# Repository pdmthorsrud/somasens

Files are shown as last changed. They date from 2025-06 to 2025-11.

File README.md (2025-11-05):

# SomaSens

A haptic feedback system that translates Pushbullet notifications into physical vibration patterns using Arduino-controlled motors.

## Hardware Photos

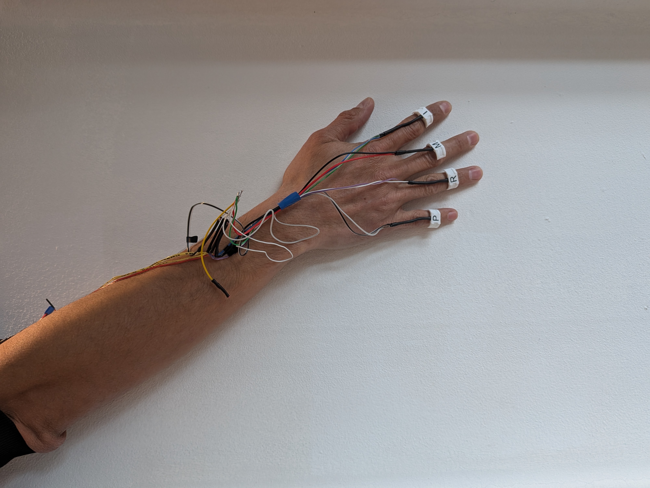
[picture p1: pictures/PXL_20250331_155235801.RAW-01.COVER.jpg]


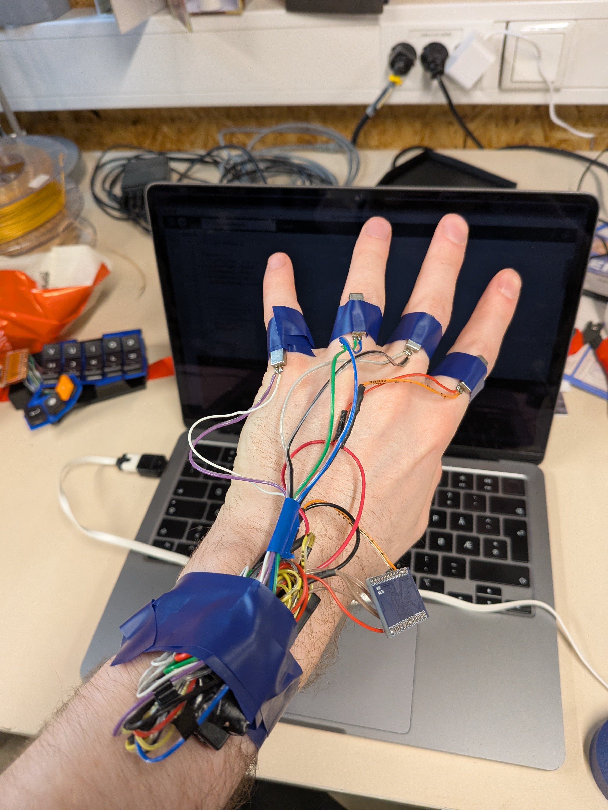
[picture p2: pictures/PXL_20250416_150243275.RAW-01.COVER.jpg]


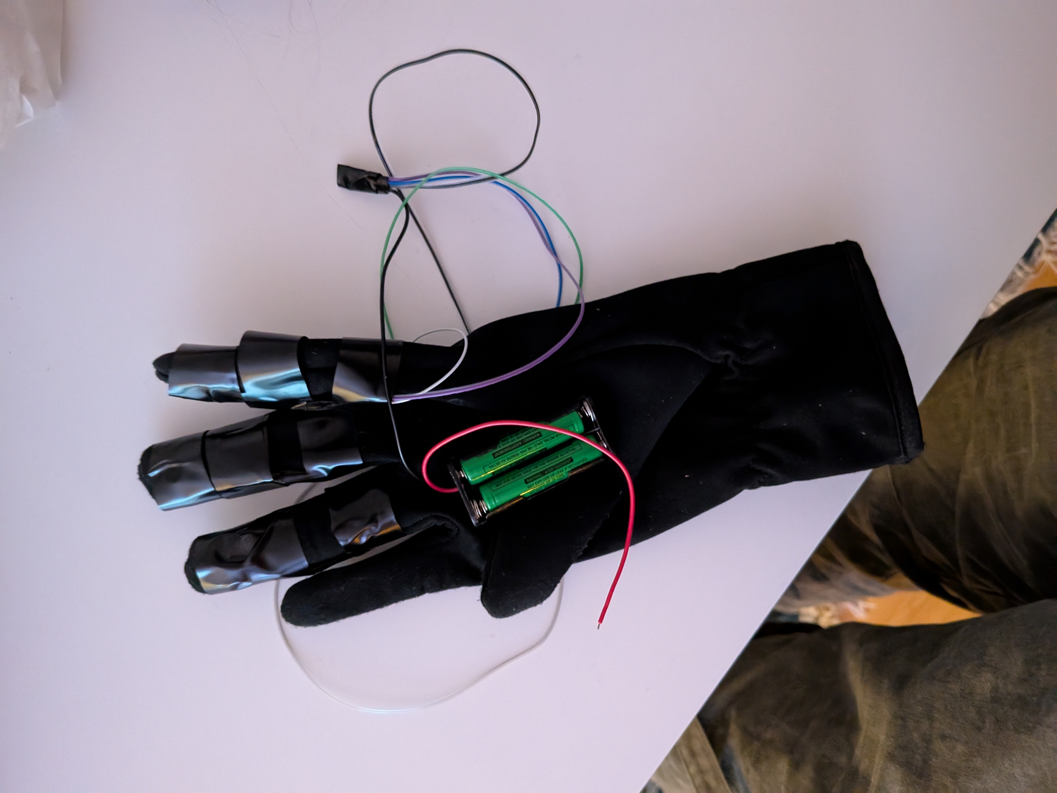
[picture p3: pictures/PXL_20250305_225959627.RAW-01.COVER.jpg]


## System Architecture

```mermaid
graph TB
    subgraph "Mobile Device"
        A[Notification Event]
    end

    subgraph "Pushbullet Cloud"
        B[Pushbullet API]
        C[WebSocket Stream]
    end

    subgraph "Python Host main.py"
        D[WebSocket Listener]
        E[Pushbullet Listener<br/>pushbullet_listener.py]
        F[Notification Interpreter]
        G[Haptic Controller<br/>haptic_controller.py]
    end

    subgraph "Arduino Hardware"
        H[Serial Interface<br/>115200 baud]
        I[Haptic HAL<br/>haptic_hal.ino]
        J1[Motor 1<br/>Pin 3]
        J2[Motor 2<br/>Pin 5]
        J3[Motor 3<br/>Pin 6]
        J4[Motor 4<br/>Pin 9]
    end

    A -->|Push Event| B
    B -->|WebSocket| C
    C -->|JSON Message| D
    D --> E
    E -->|Notification Data| F
    F -->|Haptic Pattern| G
    G -->|Serial Command<br/>v:motor:intensity:duration| H
    H --> I
    I -->|PWM Signal| J1
    I -->|PWM Signal| J2
    I -->|PWM Signal| J3
    I -->|PWM Signal| J4

    style A fill:#e1f5ff
    style B fill:#ffe1e1
    style C fill:#ffe1e1
    style D fill:#fff4e1
    style E fill:#fff4e1
    style F fill:#fff4e1
    style G fill:#fff4e1
    style H fill:#e1ffe1
    style I fill:#e1ffe1
    style J1 fill:#f0e1ff
    style J2 fill:#f0e1ff
    style J3 fill:#f0e1ff
    style J4 fill:#f0e1ff
```

## How It Works

### 1. Notification Flow

When a notification arrives on your mobile device, it flows through the system as follows:

1. **Mobile Device** generates a notification event
2. **Pushbullet** captures the notification and sends it to the cloud
3. **WebSocket Stream** broadcasts the notification in real-time
4. **Python Host** receives and processes the notification

### 2. Python Processing Layer

The Python application consists of three main components:

#### main.py
- Entry point of the application
- Manages WebSocket connection lifecycle
- Coordinates between listener and controller
- Handles graceful shutdown

#### pushbullet_listener.py
- Connects to Pushbullet WebSocket stream
- Parses incoming JSON messages
- Interprets notifications and maps them to haptic patterns
- Currently defaults to `all_vibrate` pattern for all notifications

#### haptic_controller.py
- Manages serial communication with Arduino
- Provides haptic pattern primitives:
  - `left_to_right()` - Sequential vibration from left to right
  - `right_to_left()` - Sequential vibration from right to left
  - `all_vibrate()` - Simultaneous vibration of all motors
  - `confirm()` - Double-tap pattern
  - `cancel()` - Fading pulse pattern
- Sends formatted commands over serial to Arduino

### 3. Serial Protocol

Commands are sent from Python to Arduino over serial at 115200 baud:

```
v:motor_id:intensity:duration_ms
```

Example:
```
v:1:1.0:500  # Vibrate motor 1 at 100% intensity for 500ms
```

### 4. Arduino Hardware Layer

#### haptic_hal.ino
- Receives serial commands
- Parses vibration instructions
- Controls 4 motors via PWM pins (3, 5, 6, 9)
- Manages concurrent vibration events
- Automatically stops vibrations after specified duration

The Arduino tracks active vibration events for each motor and updates them in the main loop, allowing multiple motors to vibrate simultaneously with different durations.

## Hardware Setup

### Bill of Materials

For a complete list of components and purchase links, see [BOM.md](BOM.md).

Key components:
- Pro Micro ATmega32U4 (USB Type-C)
- 4x Linear vibration motors (0619AAC, 1.2V)
- 4x IRLZ44N MOSFETs
- 18650 battery holder
- Supporting components (resistors, diodes, wire)

### Pin Configuration
- Motor 1: Pin 3 (PWM)
- Motor 2: Pin 5 (PWM)
- Motor 3: Pin 6 (PWM)
- Motor 4: Pin 9 (PWM)

## Software Setup

### Prerequisites
- Python 3.x
- Arduino IDE
- Pushbullet account and API key

### Installation

1. Install Python dependencies:
```bash
pip install -r requirements.txt
```

2. Create a `.env` file with your Pushbullet API key:
```
pushbullet_api_key=YOUR_API_KEY_HERE
```

3. Upload `haptic_hal.ino` to your Arduino

4. Update the serial port in `haptic_controller.py` if needed (default: `/dev/cu.usbmodem101`)

### Running

```bash
python main.py
```

The system will:
1. Connect to the Arduino via serial
2. Establish WebSocket connection to Pushbullet
3. Listen for notifications
4. Trigger haptic patterns when notifications arrive

Press Ctrl+C to exit gracefully.

## Haptic Pattern Examples

### Left to Right Wave
```python
pattern = left_to_right(num_motors=4, intensity=1.0, duration=100, pause_duration=50)
```

### Confirmation Double-Tap
```python
pattern = confirm(motor=1, intensity=1.0, duration=100, gap=100)
```

### All Motors Simultaneous
```python
pattern = all_vibrate(num_motors=4, intensity=0.8, duration=200)
```

## Extending the System

### Adding New Patterns

Add pattern functions to `haptic_controller.py`:

```python
def custom_pattern(num_motors: int, intensity: float = 1.0):
    pattern = []
    # Define your pattern steps here
    pattern.append({"type": "vibrate", "motor": 1, "intensity": intensity, "duration": 100})
    pattern.append({"type": "pause", "duration": 50})
    return pattern
```

### Custom Notification Mapping

Modify `interpret_notification()` in `pushbullet_listener.py`:

```python
def interpret_notification(notification_type: str, title: str, body: str) -> list:
    if "urgent" in title.lower():
        return all_vibrate(4, intensity=1.0, duration=500)
    elif "message" in notification_type:
        return left_to_right(4, pause_duration=100)
    else:
        return confirm(1)
```

## Project Structure

```
somasens/
├── main.py                    # Application entry point
├── haptic_controller.py       # Serial communication & pattern library
├── pushbullet_listener.py     # WebSocket listener & notification handler
├── haptic_hal.ino            # Arduino firmware
├── requirements.txt          # Python dependencies
├── BOM.md                    # Bill of materials with component links
├── pictures/                 # Hardware iteration photos
├── stl/                      # 3D printable models
├── .env                      # API keys (not in version control)
├── .gitignore                # Git ignore rules
└── README.md                 # This file
```

## License

This project is open source and available for educational and personal use.

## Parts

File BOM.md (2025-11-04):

# Bill of Materials (BOM)

## Electronics Components

| Qty | Component | Description | Specifications | Link |
|-----|---|---|---|---|
| 4 | Linear Vibration Motor | 0619AAC Brushless X-axis vibration motor | 1.2V, 100mA max, precision linear pulse | [AliExpress](https://www.aliexpress.com/item/1005006421331249.html) |
| 1 | Microcontroller | Pro Micro ATmega32U4 USB Type-C | 5V, 16MHz, 2-row header | [AliExpress](https://www.aliexpress.com/item/1576902211.html) |
| 4 | MOSFET Transistor | IRLZ44N TO-220 | Logic-level N-channel MOSFET for motor control | [AliExpress](https://www.aliexpress.com/item/1005007084688391.html) |
| 1 | Battery Holder | 18650 single slot battery case | 3.7V battery storage (3-pack) | [AliExpress](https://www.aliexpress.com/item/1005006283625827.html) |

## Additional Components (Not Listed)

The following components are assumed to be needed based on the circuit design:

| Qty | Component | Description | Specifications |
|-----|---|---|---|
| 4 | Resistor | Gate resistor for MOSFETs | 220Ω - 1kΩ |
| 4 | Diode | Flyback diode for motors | 1N4001 or equivalent |
| 1 | Battery | Rechargeable lithium-ion | 18650, 3.7V |
| 1 | Breadboard/PCB | For prototyping or final assembly | - |
| - | Wire | Hookup wire | 22-24 AWG solid/stranded |
| - | USB Cable | USB Type-C cable | For programming and power |

## Circuit Design Notes

### Motor Driver Circuit (per motor)

Each vibration motor requires:
- 1x IRLZ44N MOSFET (logic-level compatible with 5V Arduino pins)
- 1x Gate resistor (220Ω - 1kΩ) between Arduino pin and MOSFET gate
- 1x Flyback diode (1N4001) across motor terminals (cathode to +)

### Power Considerations

- **Arduino**: Powered via USB (5V) or battery with voltage regulator
- **Motors**: 1.2V nominal, 100mA each = 400mA total max
- **Battery**: 18650 cell (3.7V nominal, typically 2000-3500mAh)
  - Requires voltage regulation to 1.2V for motors
  - Consider using a buck converter or PWM from 5V rail with appropriate duty cycle

### Wiring

- Motor PWM pins: 3, 5, 6, 9 (Arduino Pro Micro)
- Common ground between Arduino, motors, and battery
- MOSFETs switch the negative (ground) side of motors

## Assembly Notes

1. Upload firmware to Pro Micro before final assembly
2. Test each motor individually before connecting all four
3. Ensure proper heatsinking for MOSFETs if driving motors continuously
4. Use appropriate wire gauge for motor current (22-24 AWG sufficient)
5. Include physical mounting for motors to maximize haptic feedback transfer

## Cost Estimate

Based on AliExpress listings (approximate):
- Motors: ~€15 (4x ~€3.75 each)
- Microcontroller: ~€3.63
- MOSFETs: Price varies (typically <€1 each)
- Battery holders: ~€1.30 (per 3-pack)

**Total estimated cost**: ~€25-30 USD for main components (excluding shipping, resistors, diodes, wire, etc.)

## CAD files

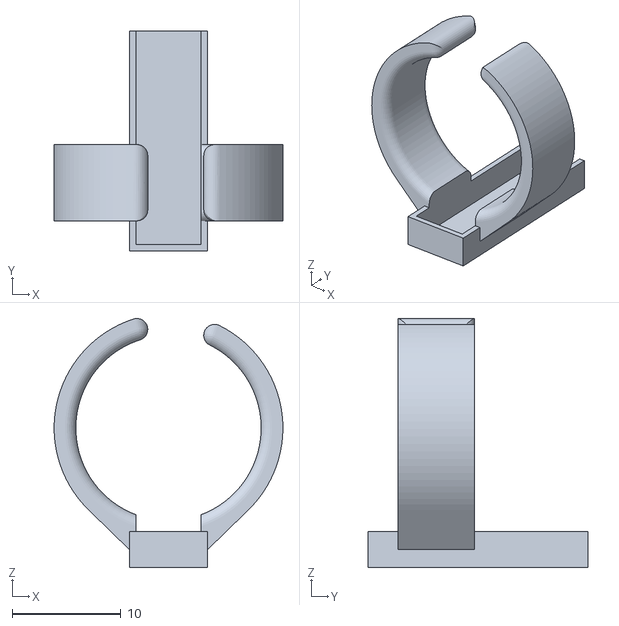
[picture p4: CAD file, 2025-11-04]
stl/ring.stl
21.0 x 20.2 x 22.8

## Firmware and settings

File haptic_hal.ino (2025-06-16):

#include <Arduino.h>

// Configuration
const int NUM_MOTORS = 4;
const int MOTOR_PINS[NUM_MOTORS] = {3, 5, 6, 9};  // PWM-capable pins
const int SERIAL_BAUD = 115200;

// Structure to track active vibration events

struct VibeEvent {
    int motor_id;      // 1-4
    float intensity;   // 0.0-1.0
    unsigned long end_time;  // millis() when vibration should stop
    bool active;       // whether this event is currently active
};

// Array to track active vibration events
VibeEvent active_events[NUM_MOTORS];

// Function declarations
void parseCommand(const String& cmd);
void startVibration(int motor_id, float intensity, unsigned long duration_ms);
void stopVibration(int motor_id);
void updateActiveVibrations();

void setup() {
    // Initialize serial
    Serial.begin(SERIAL_BAUD);
    while (!Serial) {
        ; // wait for serial port to connect
    }
    
    // Initialize motor pins
    for (int i = 0; i < NUM_MOTORS; i++) {
        pinMode(MOTOR_PINS[i], OUTPUT);
        digitalWrite(MOTOR_PINS[i], LOW);
    }
    
    // Initialize event array
    for (int i = 0; i < NUM_MOTORS; i++) {
        active_events[i].motor_id = i + 1;
        active_events[i].active = false;
    }
    
    Serial.println("Haptic HAL Ready");
}

void loop() {
    // Check for incoming commands
    if (Serial.available()) {
        String cmd = Serial.readStringUntil('\n');
        parseCommand(cmd);
    }
    
    // Update active vibrations
    updateActiveVibrations();
}

void parseCommand(const String& cmd) {
    // Check if command starts with 'v:'
    if (!cmd.startsWith("v:")) {
        Serial.println("Error: Invalid command format.);
        return;
    }
    
    // Parse command components
    int motor_id = cmd.substring(2).toInt();
    int intensity_start = cmd.indexOf(':', 2) + 1;
    int duration_start = cmd.indexOf(':', intensity_start) + 1;
    
    if (motor_id < 1 || motor_id > NUM_MOTORS) {
        Serial.println("Error: Invalid motor ID");
        return;
    }
    
    float intensity = cmd.substring(intensity_start, duration_start - 1).toFloat();
    unsigned long duration_ms = cmd.substring(duration_start).toInt();
    
    // Validate intensity
    if (intensity < 0.0 || intensity > 1.0) {
        Serial.println("Error: Intensity out of range");
        return;
    }
    
    // Start vibration
    startVibration(motor_id, intensity, duration_ms);
}

void startVibration(int motor_id, float intensity, unsigned long duration_ms) {
    // Convert motor_id (1-4) to array index (0-3)
    int idx = motor_id - 1;
    
    // Calculate PWM value (0-255)
    int pwm_value = (int)(intensity * 255);
    
    // Set up new vibration event
    active_events[idx].intensity = intensity;
    active_events[idx].end_time = millis() + duration_ms;
    active_events[idx].active = true;
    
    // Start motor
    digitalWrite(MOTOR_PINS[idx], pwm_value);
}

void stopVibration(int motor_id) {
    int idx = motor_id - 1;
    active_events[idx].active = false;
    digitalWrite(MOTOR_PINS[idx], 0);
}

void updateActiveVibrations() {
    unsigned long current_time = millis();
    
    // Check each motor for expired vibrations
    for (int i = 0; i < NUM_MOTORS; i++) {
        if (active_events[i].active && current_time >= active_events[i].end_time) {
            stopVibration(active_events[i].motor_id);
        }
    }
} 

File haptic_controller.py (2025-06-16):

import time
import serial

class HapticController:
    def __init__(self, port='/dev/cu.usbmodem101', baudrate=115200):
        self.serial = serial.Serial(port, baudrate, timeout=1)
        print(f"Connected to {port} at {baudrate} baud")
        # Wait for Arduino to initialize
        time.sleep(2)

    def send_vibration_command(self, motor_id: int, intensity: float, duration_ms: int):
        """Send a vibration command to motor ID."""
        cmd = f"v:{motor_id}:{intensity}:{duration_ms}\n"
        self.serial.write(cmd.encode())
        
        # # Wait for response or timeout
        # response = self.serial.readline().decode().strip()
        # if response:
        #     print(f"Response: {response}")

    def send_pause(self, motor_id: int, duration_ms: int):
        """Send a pause command to a specific motor."""
        cmd = f"p:{motor_id}:{duration_ms}\n"
        self.serial.write(cmd.encode())

    def run_pattern(self, pattern: list):
        """Run a pattern of vibration steps and pauses."""
        for step in pattern:
            if step["type"] == "pause":
                time.sleep(step["duration"] / 1000)  # Convert ms to seconds
            elif step["type"] == "vibrate":
                self.send_vibration_command(step["motor"], step["intensity"], step["duration"])
                time.sleep(step["duration"] / 1000)

    def close(self):
        """Close the serial connection."""
        self.serial.close()

# Sample patterns
def left_to_right(num_motors: int, intensity: float = 1.0, duration: int = 1, pause_duration: int = 100):
    """Create a pattern that vibrates motors from left to right with pauses between steps."""
    pattern = []
    for i in range(1, num_motors + 1):
        pattern.append({"type": "vibrate", "motor": i, "intensity": intensity, "duration": duration})
        if i < num_motors:  # Don't add pause after the last vibration
            pattern.append({"type": "pause", "duration": pause_duration})
    return pattern

def right_to_left(num_motors: int, intensity: float = 1.0, duration: int = 1, pause_duration: int = 100):
    """Create a pattern that vibrates motors from right to left with pauses between steps."""
    pattern = []
    for i in range(num_motors, 0, -1):
        pattern.append({"type": "vibrate", "motor": i, "intensity": intensity, "duration": duration})
        if i > 1:  # Don't add pause after the last vibration
            pattern.append({"type": "pause", "duration": pause_duration})
    return pattern

def all_vibrate(num_motors: int, intensity: float = 1.0, duration: int = 1):
    """Create a pattern that vibrates all motors simultaneously."""
    pattern = []
    # First vibrate all motors
    for i in range(1, num_motors + 1):
        pattern.append({"type": "vibrate", "motor": i, "intensity": intensity, "duration": duration})
    return pattern

def confirm(motor: int, intensity: float = 1.0, duration: int = 1, gap: int = 100):
    """Double-tap pattern to confirm an action."""
    return [
        {"type": "vibrate", "motor": motor, "intensity": intensity, "duration": duration},
        {"type": "pause", "duration": gap},
        {"type": "vibrate", "motor": motor, "intensity": intensity, "duration": duration}
    ]

def cancel(motor: int, intensity: float = 1.0, duration: int = 300):
    """Strong pulse fade to signify cancellation or negation."""
    return [
        {"type": "vibrate", "motor": motor, "intensity": intensity, "duration": duration},
        {"type": "pause", "duration": 200},
        {"type": "vibrate", "motor": motor, "intensity": intensity * 0.5, "duration": duration},
        {"type": "pause", "duration": 200},
        {"type": "vibrate", "motor": motor, "intensity": intensity * 0.25, "duration": duration}
    ]


# Example usage
if __name__ == "__main__":
    try:
        controller = HapticController()
        
        # Run sample patterns
        num_motors = 4
        
        controller.run_pattern(left_to_right(num_motors, pause_duration=200))
        controller.run_pattern(right_to_left(num_motors, pause_duration=200))
        controller.run_pattern(all_vibrate(num_motors))
        
    except KeyboardInterrupt:
        pass
    finally:
        controller.close() 

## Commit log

2025-11-04 Restructure project and add comprehensive documentation
    - Moved files from dsl/ subdirectory to project root
    - Added comprehensive README with system architecture
    - Included Mermaid diagram showing complete data flow
    - Added .gitignore to exclude __pycache__ and .env files
    - Documented all components: notification flow, Python processing, serial protocol, and Arduino hardware layer
2025-11-04 Add bill of materials and hardware documentation
    - Created BOM.md with complete component list and AliExpress links
    - Includes 4x vibration motors, Pro Micro, MOSFETs, battery holder
    - Added circuit design notes and cost estimates
    - Updated README to reference BOM and hardware iterations
    - Added pictures/ directory with hardware iteration photos
    - Updated .gitignore to exclude .DS_Store files
    - Documented stl/ directory for 3D printable models
    [ring.stl]
